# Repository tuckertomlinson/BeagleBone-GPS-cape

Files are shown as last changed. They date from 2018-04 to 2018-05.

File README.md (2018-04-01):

PCB layout for a GPS cape for the beaglebone black.

This is a home project. There is NO garauntee that the circuits do what
is intended, or that the function is adequately documented.

Any use of the files found in this project should be accompanied by a 
thorough review to determine proper function and fitness for use.

Project goals:
- clock discipline for the Beaglebone family such that a beaglebone with cape
	may act as an NTP stratum1 timeserver on a local network
- Use a GPS module to generate a 1 PPS signal that is synced to the atomic 
	clocks. The GPS module should interface with an active antenna so that
	good satellite lock may be attained indoors.
- provide an accurate RTC via a stand-alone i2c RTC module
- Hardware will be provided on a PCB cape, using SMT components for tight layout
	and low cost.
- Provide a hardware overlay file that may be enabled in uEnv.txt that will 
	automatically configure the correct pins for PPS capture, and RTC 
	connection

Stretch goals:
- Included a voltage regulated clock source, and force the BB to use the external 
	clock for better frequency stability

Current status:
- Proof of concept based on Adafruit Ultimate GPS breakout constructed and working
- 2 hardware capes designed
	- low cost cape based on Sierra Wireless XM1100 module
		- includeds RTC, and active antenna circuit
	- High cost cape based on uBlox LEA-M8T module
		- includes RTC, and 24Mhz VCTCXO clock. 
		- GPS module provides active antenna power
- Capes use Uart 4 to recieve GPS packets, and timer4 to take in PPS
- RTC is on i2c 1

Both capes completely untested.

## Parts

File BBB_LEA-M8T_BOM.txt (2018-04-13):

BeagleBone LEA-M8T GPS timing cape BOM:
notes: 
1)almost no effort was given here to cost optimization. Caps and resistors may likely be substituted for alternative components at lower cost. 
2)cost reflects prices on Digikey as of the time that this BOM was compiled. Prices reflect single part quantity. discounts for bulk purchases are not taken into account

part: 			board ID			manuf		manuf. #		digikey#		cost Apr 2018 	link
GPS module		U$1				uBlox		LEA-M8T			672-1067-1-ND 		$89		https://www.digikey.com/product-detail/en/u-blox-america-inc/LEA-M8T/672-1067-1-ND/7931818
.01uF cap 0805		C1,C4,C6,C9,C10,C13,C16,C18	TDK		CGA4J2X8R1H104K125AA 	445-5909-1-ND 		$0.22		https://www.digikey.com/product-detail/en/tdk-corporation/CGA4J2X8R1H104K125AA/445-5909-1-ND/2443949
10uF cap 0805		C2,C3,C5,C7,C11,C12,C14,C15,C17	TDK		C2012X7R1A106K125AE 	445-173616-1-ND		$0.46		https://www.digikey.com/product-detail/en/tdk-corporation/C2012X7R1A106K125AE/445-173616-1-ND/5809687
10nF cap 0805		C8				TDK		C2012X7R2E103K125AA 	445-2280-1-ND 		$0.21		https://www.digikey.com/product-detail/en/tdk-corporation/C2012X7R2E103K125AA/445-2280-1-ND/789789	
10kohm Resistor 0805	R2,R3,R4,R5			Panasonic	ERA-6AEB103V		P10KDACT-ND 		$0.36		https://www.digikey.com/product-detail/en/panasonic-electronic-components/ERA-6AEB103V/P10KDACT-ND/1465971
10 ohm Resistor 0805	R1				Vishay		TNPW080510R0FEEA	541-3916-1-ND 		$0.42		https://www.digikey.com/product-detail/en/vishay-dale/TNPW080510R0FEEA/541-3916-1-ND/7355274
Ferrite bead	0603	FB1,FB2,FB3,FB4,FB5		Laird		HI0805O121R-10		240-2393-1-ND		$0.11		https://www.digikey.com/product-detail/en/laird-signal-integrity-products/HI0805O121R-10/240-2393-1-ND/806753
3.3V regulator		U2				Microchip 	MIC5225-3.3		576-2980-1-ND 		$0.41		https://www.digikey.com/product-detail/en/microchip-technology/MIC5225-3.3YM5-TR/576-2980-1-ND/1815455
RTC			DS3231				Maxim		Ds3231MZ+		DS3231MZ+-ND		$7.72		https://www.digikey.com/product-detail/en/maxim-integrated/DS3231MZ/DS3231MZ-ND/2754396
24Mhz VCTCXO		U$3				Taitien		TWEAALSANF-24.000000	1664-1226-ND		$9.81		https://www.digikey.com/product-detail/en/taitien/TWEAALSANF-24.000000/1664-1226-ND/6127033
U.FL Antenna jack	U$20				TE Connectivity	1909763-1 		 A118077CT-ND		$0.49		https://www.digikey.com/product-detail/en/te-connectivity-amp-connectors/1909763-1/A118077CT-ND/4729711	
2X pinhdr 2x23		U$15				Samtec		SSQ-123-03-G-D		SAM1196-23-ND		$9.11		https://www.digikey.com/product-detail/en/samtec-inc/SSQ-123-03-G-D/SAM1196-23-ND/1111439  alt: https://www.adafruit.com/product/706
Diode			D1				Diodes Inc	1N4148WS-7-F		1N4148WS-FDICT-ND	$0.19		https://www.digikey.com/product-detail/en/diodes-incorporated/1N4148WS-7-F/1N4148WS-FDICT-ND/815281
Diode			D2				Toshiba		CUS520,H3F		CUS520H3FCT-ND		$0.22		https://www.digikey.com/product-detail/en/toshiba-semiconductor-and-storage/CUS520H3F/CUS520H3FCT-ND/5114381
CR1220 batt. holder	B1				MPD		BK-885 			BK-885-ND		$0.35		https://www.digikey.com/products/en?keywords=3001k-nd

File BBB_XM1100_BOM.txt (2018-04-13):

BeagleBone LEA-M8T GPS timing cape BOM:
notes: 
1)almost no effort was given here to cost optimization. Caps and resistors may likely be substituted for alternative components at lower cost. 
2)cost reflects prices on Digikey as of the time that this BOM was compiled. Prices reflect single part quantity. discounts for bulk purchases are not taken into account

part: 			board ID			manuf		manuf. #		digikey#		cost Apr 2018 	link
GPS module		U$3				Sierra		XXM1100_1103874		 1645-1040-1-ND 	$12.98		https://www.digikey.com/product-detail/en/sierra-wireless/XM1100_1103874/1645-1040-1-ND/7801768		
10uF cap 0805		C1,C2,C3,C6			TDK		C2012X7R1A106K125AE 	445-173616-1-ND		$0.46		https://www.digikey.com/product-detail/en/tdk-corporation/C2012X7R1A106K125AE/445-173616-1-ND/5809687
0.1uF cap 0805		C5,C7				TDK		CGA4J2X8R1H104K125AA 	445-5909-1-ND 		$0.22		https://www.digikey.com/product-detail/en/tdk-corporation/CGA4J2X8R1H104K125AA/445-5909-1-ND/2443949
47pF cap 0805		C4				ATC		600F470FT250XT  	1284-1061-1-ND 		$2.25		https://www.digikey.com/product-detail/en/american-technical-ceramics/600F470FT250XT/1284-1061-1-ND/3905433	
10kohm Resistor 0805	R1,R2,R3,R4,R5			Panasonic	ERA-6AEB103V		P10KDACT-ND 		$0.36		https://www.digikey.com/product-detail/en/panasonic-electronic-components/ERA-6AEB103V/P10KDACT-ND/1465971
10 ohm Resistor 0805	R6				Vishay		TNPW080510R0FEEA	541-3916-1-ND 		$0.42		https://www.digikey.com/product-detail/en/vishay-dale/TNPW080510R0FEEA/541-3916-1-ND/7355274
Ferrite bead	0805	FB1,FB2				Laird		HI0805O121R-10		240-2393-1-ND		$0.11		https://www.digikey.com/product-detail/en/laird-signal-integrity-products/HI0805O121R-10/240-2393-1-ND/806753
39nH inductor 0805	L1				Abracon		AISC-0805HQ-39NJ-T	535-12362-1-ND		$0.40		https://www.digikey.com/product-detail/en/murata-electronics-north-america/LQW18ANR15J8ZD/490-15773-1-ND/6800438
3.3V regulator		U2				Microchip 	MIC5225-3.3		576-2980-1-ND 		$0.41		https://www.digikey.com/product-detail/en/microchip-technology/MIC5225-3.3YM5-TR/576-2980-1-ND/1815455
RTC			DS3231				Maxim		Ds3231MZ+		DS3231MZ+-ND		$7.72		https://www.digikey.com/product-detail/en/maxim-integrated/DS3231MZ/DS3231MZ-ND/2754396
U.FL Antenna jack	U$20				TE Connectivity	1909763-1 		 A118077CT-ND		$0.49		https://www.digikey.com/product-detail/en/te-connectivity-amp-connectors/1909763-1/A118077CT-ND/4729711	
2X pinhdr 2x23		U$15				Samtec		SSQ-123-03-G-D		SAM1196-23-ND		$9.11		https://www.digikey.com/product-detail/en/samtec-inc/SSQ-123-03-G-D/SAM1196-23-ND/1111439  alt: https://www.adafruit.com/product/706
Diode			D1				Diodes Inc	1N4148WS-7-F		1N4148WS-FDICT-ND	$0.19		https://www.digikey.com/product-detail/en/diodes-incorporated/1N4148WS-7-F/1N4148WS-FDICT-ND/815281
Diode			D2				Toshiba		CUS520,H3F		CUS520H3FCT-ND		$0.22		https://www.digikey.com/product-detail/en/toshiba-semiconductor-and-storage/CUS520H3F/CUS520H3FCT-ND/5114381
CR1220 batt. holder	B1				MPD		BK-885 			BK-885-ND		$0.35		https://www.digikey.com/products/en?keywords=3001k-nd

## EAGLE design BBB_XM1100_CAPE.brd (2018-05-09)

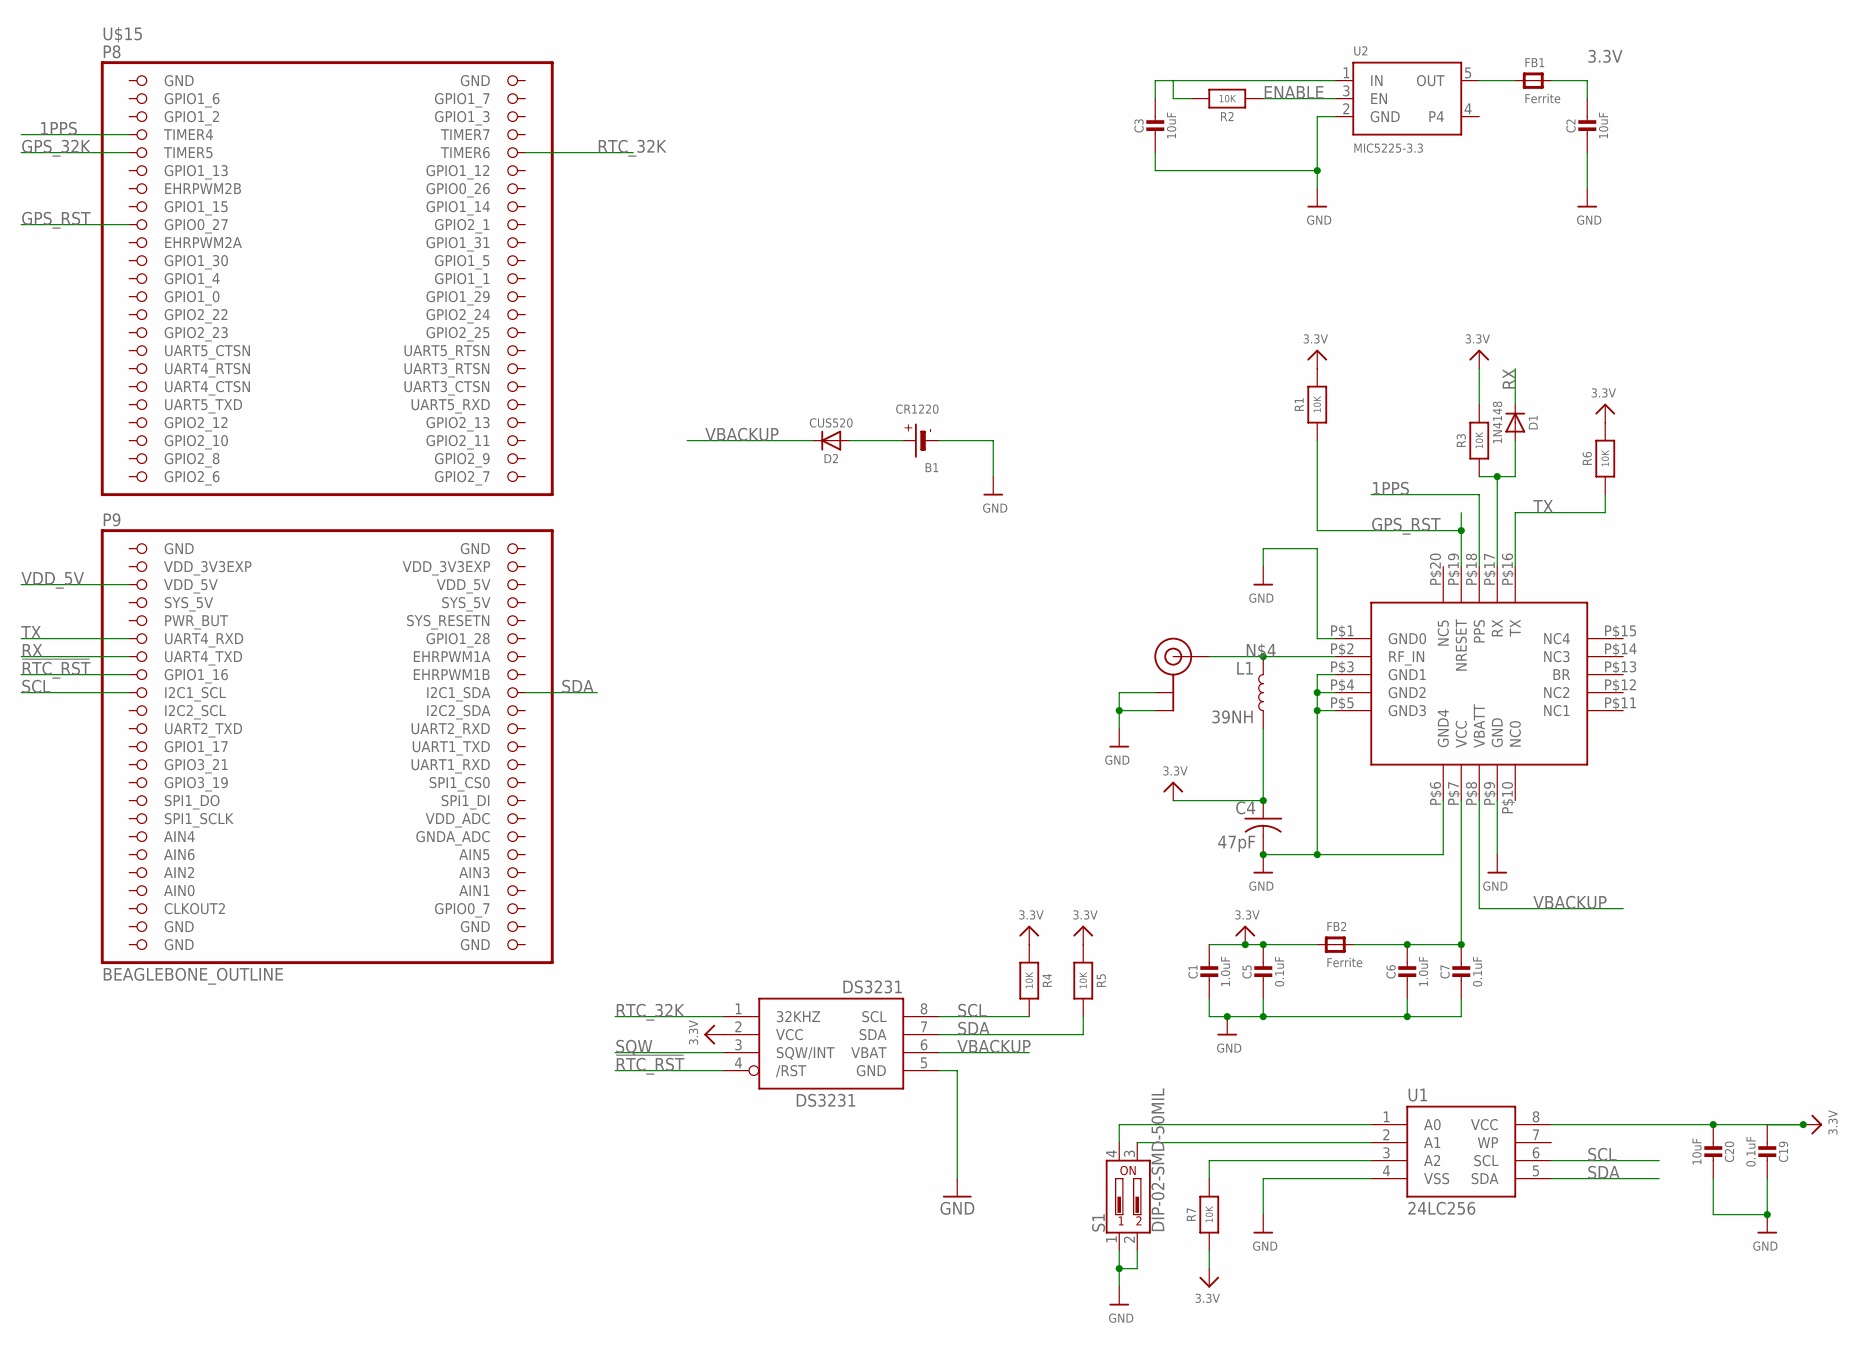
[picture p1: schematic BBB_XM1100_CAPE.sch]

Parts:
B1: CR1220
C1, C6: 1.0uF; 0805-NO
C2, C3, C20: 10uF; 0805-NO
C4: 47pF; C0805
C5, C7, C19: 0.1uF; 0805-NO
D1: 1N4148; SOD-323
D2: CUS520; SOD-323
DS3231: DS3231M-8PIN; SO08
FB1, FB2: Ferrite; 0805-NO@1
L1: 39NH; 0402
R1, R2, R3, R4, R5, R6, R7: 10K; 0805-NO
S1: DIP-02-SMD-50MIL; DIPSWITCH-02-50MIL
U1: 24LC256; SO08
U2: MIC5225-3.3; SOT23-5
U$3: XM1100
U$15: BEAGLEBONE_OUTLINE; BEAGLEBONE_SHIELD
U$20: U.FL

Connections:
1PPS: U$3.P$18 (PPS), U$15.7 (TIMER4)
3.3V: C1.1, C2.1, C4.1, C5.1, C19.1, C20.1, DS3231.2 (VCC), FB1.2, FB2.1, L1.2, R1.1, R3.1, R4.1, R5.1, R6.1, R7.1, U1.8 (VCC)
!RTC_RST: DS3231.4 (/RST), U$15.61 (GPIO1_16)
AIN0: U$15.85 (AIN0)
ENABLE: R2.1, U2.3 (EN)
GND: B1.-, C1.2, C2.2, C3.2, C4.2, C5.2, C6.2, C7.2, C19.2, C20.2, DS3231.5 (GND), S1.1, S1.2, U1.4 (VSS), U2.2 (GND), U$3.P$1 (GND0), U$3.P$3 (GND1), U$3.P$4 (GND2), U$3.P$5 (GND3), U$3.P$6 (GND4), U$3.P$9 (GND), U$15.1 (GND), U$15.2 (GND), U$15.47 (GND), U$15.48 (GND), U$15.89 (GND), U$15.90 (GND), U$15.91 (GND), U$15.92 (GND), U$20.P$1 (GND), U$20.P$2 (GND)
GPS_32K: U$15.9 (TIMER5)
GPS_RST: R1.2, U$3.P$19 (NRESET), U$15.17 (GPIO0_27)
unnamed: B1.+$1 (+), D2.A
unnamed: FB1.1, U2.5 (OUT)
unnamed: L1.1, U$3.P$2 (RF_IN), U$20.P$3 (SIGNAL)
unnamed: C6.1, C7.1, FB2.2, U$3.P$7 (VCC)
unnamed: R7.2, U1.3 (A2)
unnamed: S1.3, U1.2 (A1)
unnamed: S1.4, U1.1 (A0)
RTC_32K: DS3231.1 (32KHZ), U$15.10 (TIMER6)
RX: D1.C, U$15.59 (UART4_TXD)
RX_3V: D1.A, R3.2, U$3.P$17 (RX)
SCL: DS3231.8 (SCL), R4.2, U1.6 (SCL), U$15.63 (I2C1_SCL)
SDA: DS3231.7 (SDA), R5.2, U1.5 (SDA), U$15.64 (I2C1_SDA)
SQW: DS3231.3 (SQW/INT)
SYS_5V: U$15.53 (SYS_5V)
TX: R6.2, U$3.P$16 (TX), U$15.57 (UART4_RXD)
VBACKUP: D2.C, DS3231.6 (VBAT), U$3.P$8 (VBATT)
VDD_3V3EXP: U$15.49 (VDD_3V3EXP), U$15.50 (VDD_3V3EXP)
VDD_5V: C3.1, R2.2, U2.1 (IN), U$15.51 (VDD_5V), U$15.52 (VDD_5V)

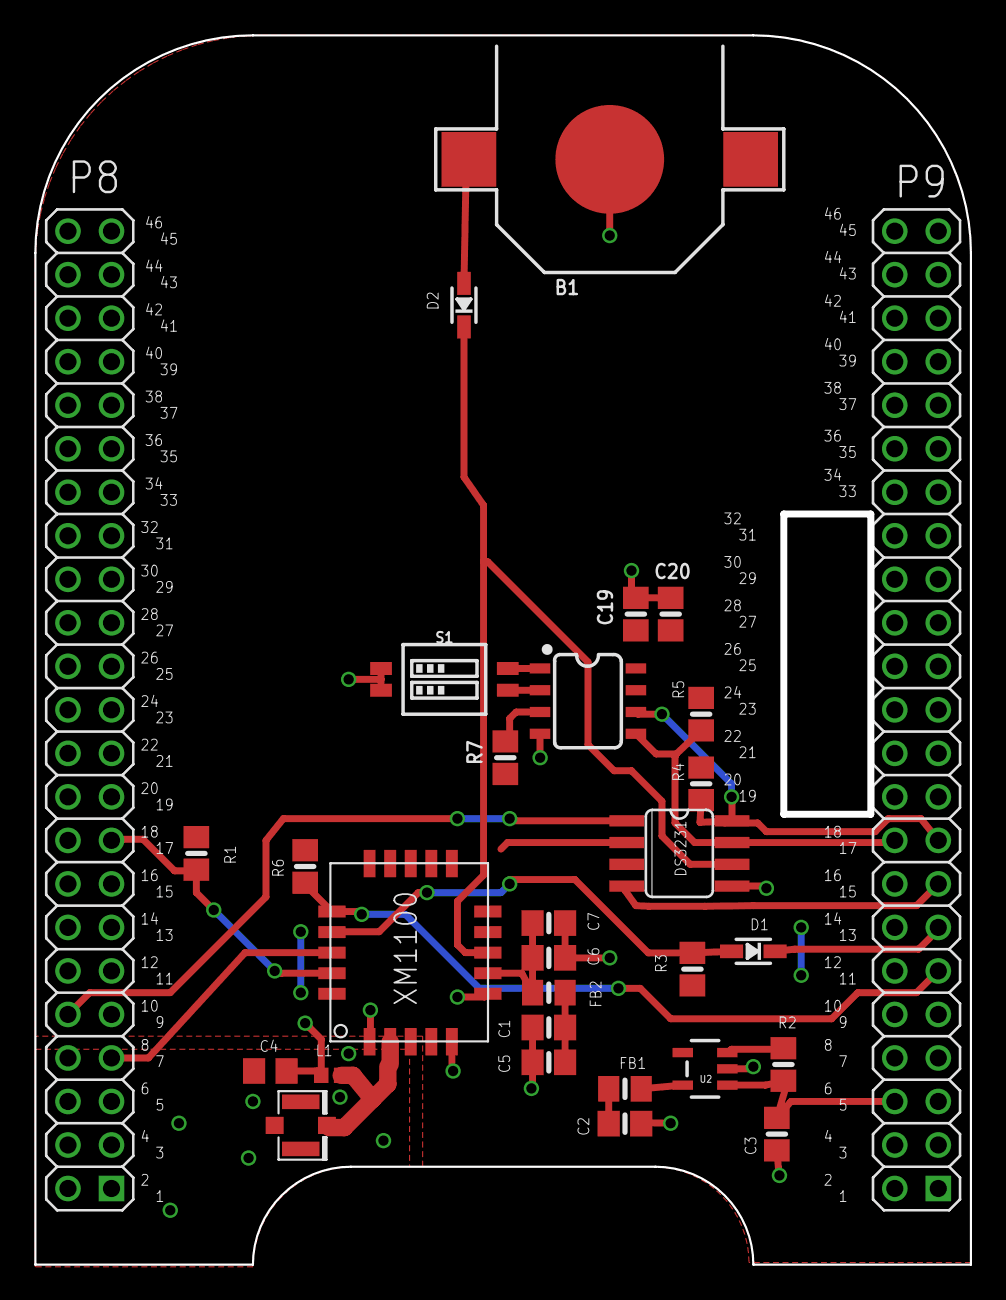
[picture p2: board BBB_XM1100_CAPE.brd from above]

Board: 2 copper layers, 54.6 x 71.8 mm, 29 parts (0 on the bottom side), 22 nets.

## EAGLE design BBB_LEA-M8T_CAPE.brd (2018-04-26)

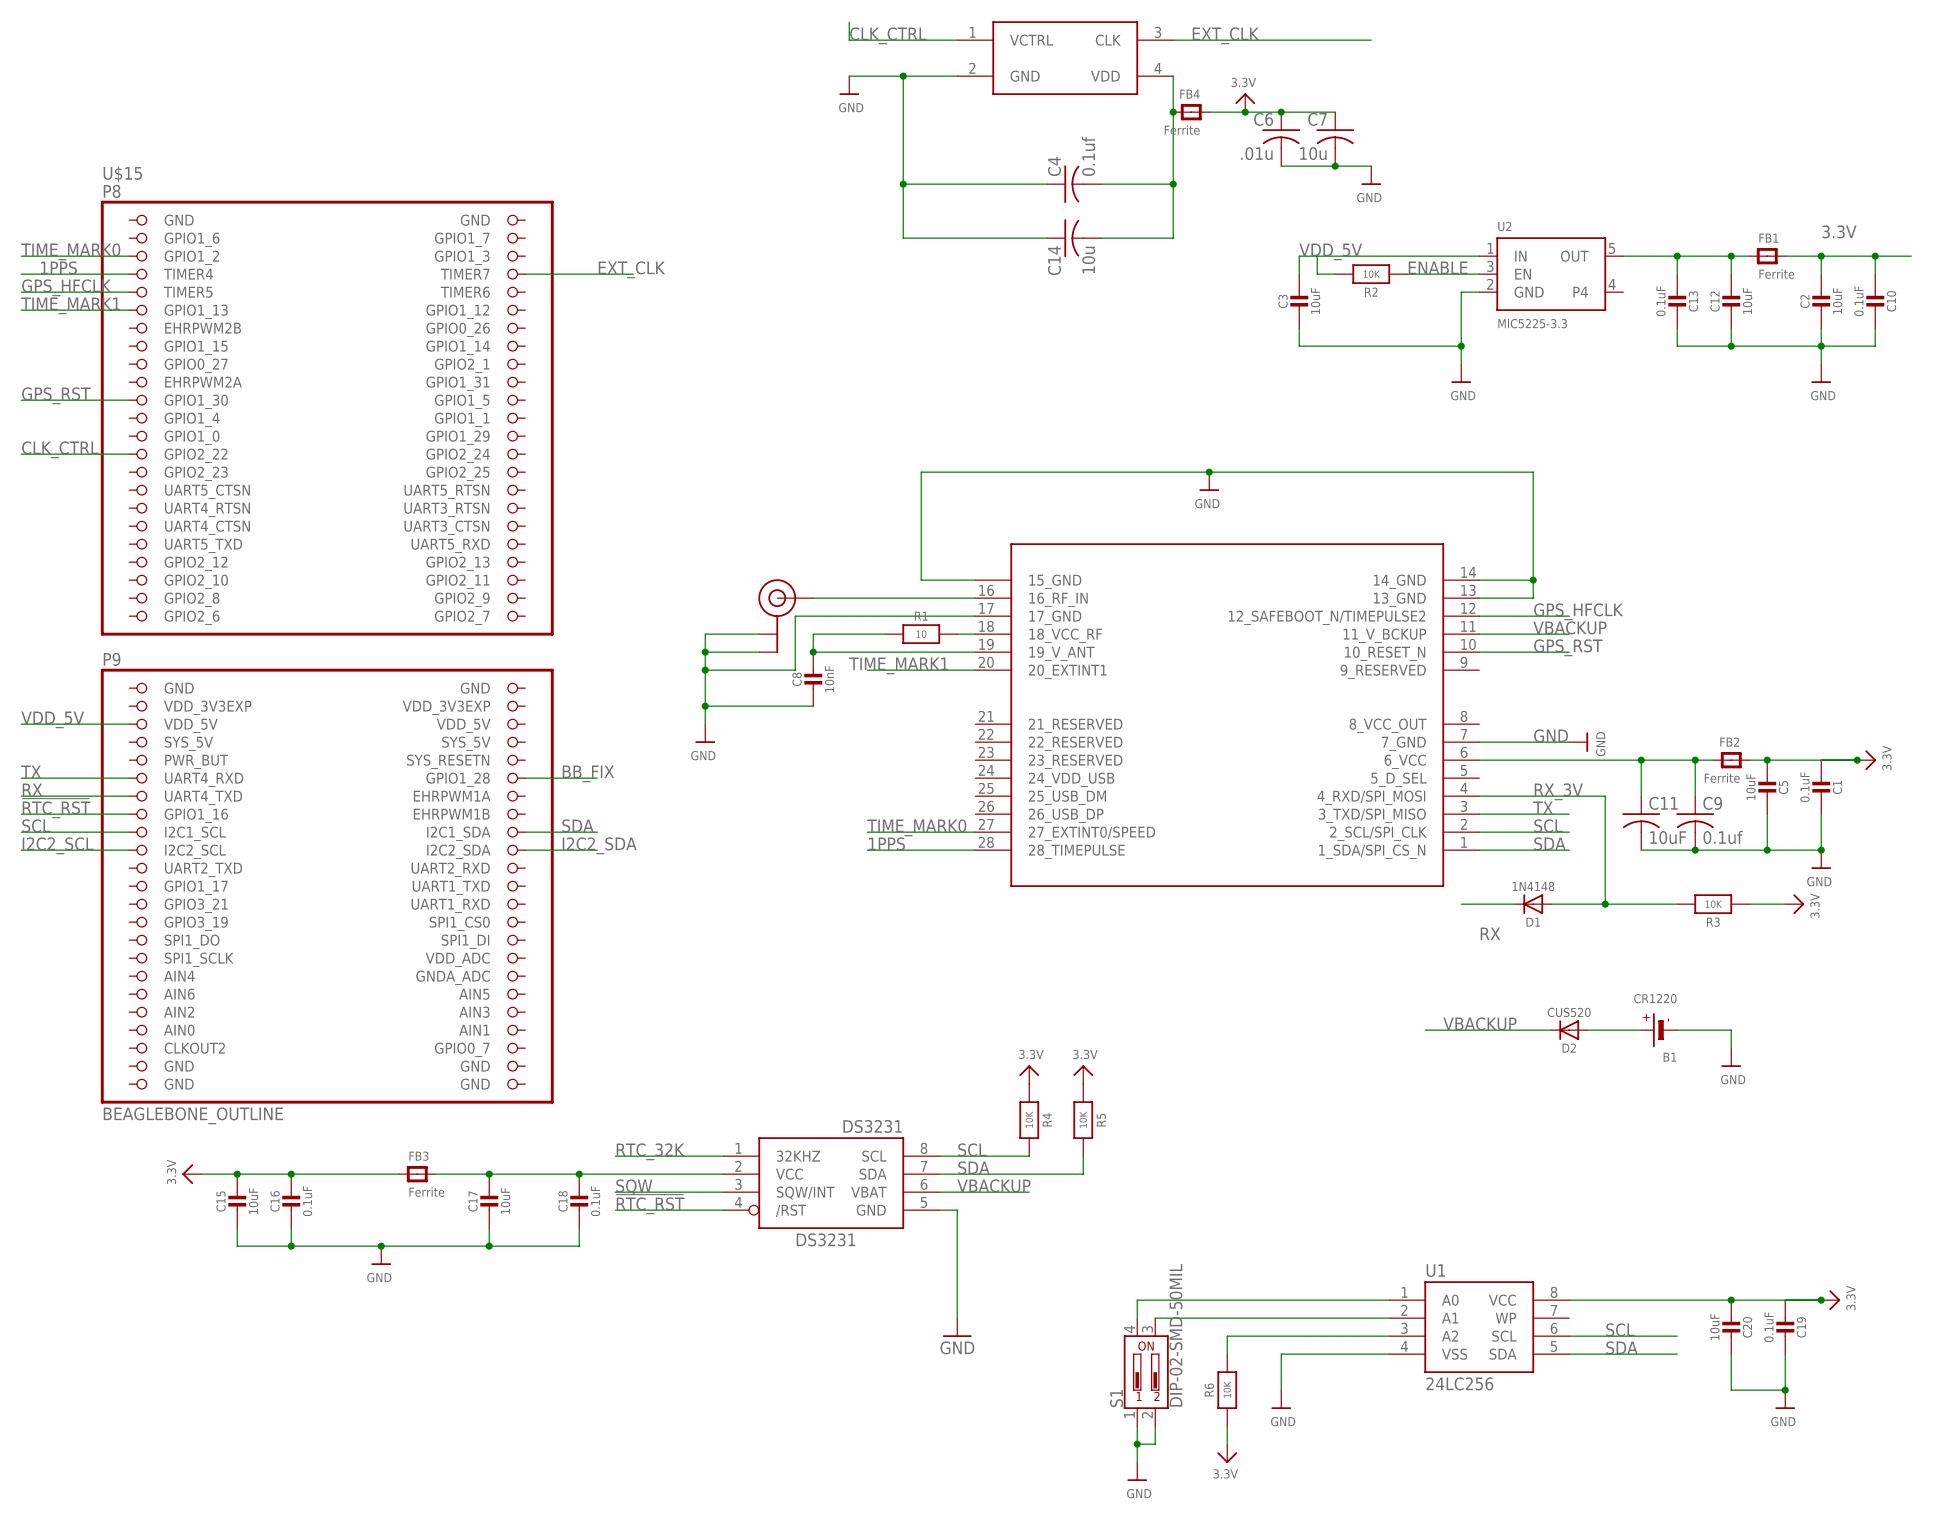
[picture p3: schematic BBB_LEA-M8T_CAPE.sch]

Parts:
B1: CR1220
C1, C10, C13, C16, C18, C19: 0.1uF; 0805-NO
C2, C3, C5, C12, C15, C17, C20: 10uF; 0805-NO
C4, C9: 0.1uf; C0805
C6: .01u; C0805
C7, C14: 10u; C0805
C8: 10nF; 0805-NO
C11: 10uF; C0805
D1: 1N4148; SOD-323
D2: CUS520; SOD-323
DS3231: DS3231M-8PIN; SO08
FB1, FB2, FB3, FB4: Ferrite; 0805-NO@1
R1: 10; 0805-NO
R2, R3, R4, R5, R6: 10K; 0805-NO
S1: DIP-02-SMD-50MIL; DIPSWITCH-02-50MIL
U1: 24LC256; SO08
U2: MIC5225-3.3; SOT23-5
U$1: LEA-M8
U$3: TAITIEN_TW-SERIES_OSCILLATOR
U$15: BEAGLEBONE_OUTLINE; BEAGLEBONE_SHIELD
U$20: U.FL

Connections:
1PPS: U$1.28 (28_TIMEPULSE), U$15.7 (TIMER4)
3.3V: C1.1, C2.1, C5.1, C6.1, C7.1, C10.1, C15.1, C16.1, C19.1, C20.1, FB1.2, FB2.1, FB3.1, FB4.1, R3.1, R4.1, R5.1, R6.1, U1.8 (VCC)
!RTC_RST: DS3231.4 (/RST), U$15.61 (GPIO1_16)
AIN0: U$15.85 (AIN0)
BB_FIX: U$15.58 (GPIO1_28)
CLK_CTRL: U$3.1 (VCTRL), U$15.27 (GPIO2_22)
ENABLE: R2.1, U2.3 (EN)
EXT_CLK: U$3.3 (CLK), U$15.8 (TIMER7)
GND: B1.-, C1.2, C2.2, C3.2, C4.1, C5.2, C6.2, C7.2, C8.2, C9.2, C10.2, C11.2, C12.2, C13.2, C14.1, C15.2, C16.2, C17.2, C18.2, C19.2, C20.2, DS3231.5 (GND), S1.1, S1.2, U1.4 (VSS), U2.2 (GND), U$1.7 (7_GND), U$1.13 (13_GND), U$1.14 (14_GND), U$1.15 (15_GND), U$1.17 (17_GND), U$3.2 (GND), U$15.1 (GND), U$15.2 (GND), U$15.47 (GND), U$15.48 (GND), U$15.89 (GND), U$15.90 (GND), U$15.91 (GND), U$15.92 (GND), U$20.P$1 (GND), U$20.P$2 (GND)
GPS_HFCLK: U$1.12 (12_SAFEBOOT_N/TIMEPULSE2), U$15.9 (TIMER5)
GPS_RST: U$1.10 (10_RESET_N), U$15.21 (GPIO1_30)
I2C2_SCL: U$15.65 (I2C2_SCL)
I2C2_SDA: U$15.66 (I2C2_SDA)
unnamed: B1.+$1 (+), D2.A
unnamed: C9.1, C11.1, FB2.2, U$1.6 (6_VCC)
unnamed: C12.1, C13.1, FB1.1, U2.5 (OUT)
unnamed: U$1.16 (16_RF_IN), U$20.P$3 (SIGNAL)
unnamed: C4.2, C14.2, FB4.2, U$3.4 (VDD)
unnamed: C17.1, C18.1, DS3231.2 (VCC), FB3.2
unnamed: R6.2, U1.3 (A2)
unnamed: S1.3, U1.2 (A1)
unnamed: S1.4, U1.1 (A0)
unnamed: R1.2, U$1.18 (18_VCC_RF)
unnamed: C8.1, R1.1, U$1.19 (19_V_ANT)
RTC_32K: DS3231.1 (32KHZ)
RX: D1.C, U$15.59 (UART4_TXD)
RX_3V: D1.A, R3.2, U$1.4 (4_RXD/SPI_MOSI)
SCL: DS3231.8 (SCL), R4.2, U1.6 (SCL), U$1.2 (2_SCL/SPI_CLK), U$15.63 (I2C1_SCL)
SDA: DS3231.7 (SDA), R5.2, U1.5 (SDA), U$1.1 (1_SDA/SPI_CS_N), U$15.64 (I2C1_SDA)
SQW: DS3231.3 (SQW/INT)
SYS_5V: U$15.53 (SYS_5V)
TIME_MARK0: U$1.27 (27_EXTINT0/SPEED), U$15.5 (GPIO1_2)
TIME_MARK1: U$1.20 (20_EXTINT1), U$15.11 (GPIO1_13)
TX: U$1.3 (3_TXD/SPI_MISO), U$15.57 (UART4_RXD)
VBACKUP: D2.C, DS3231.6 (VBAT), U$1.11 (11_V_BCKUP)
VDD_3V3EXP: U$15.49 (VDD_3V3EXP), U$15.50 (VDD_3V3EXP)
VDD_5V: C3.1, R2.2, U2.1 (IN), U$15.51 (VDD_5V), U$15.52 (VDD_5V)

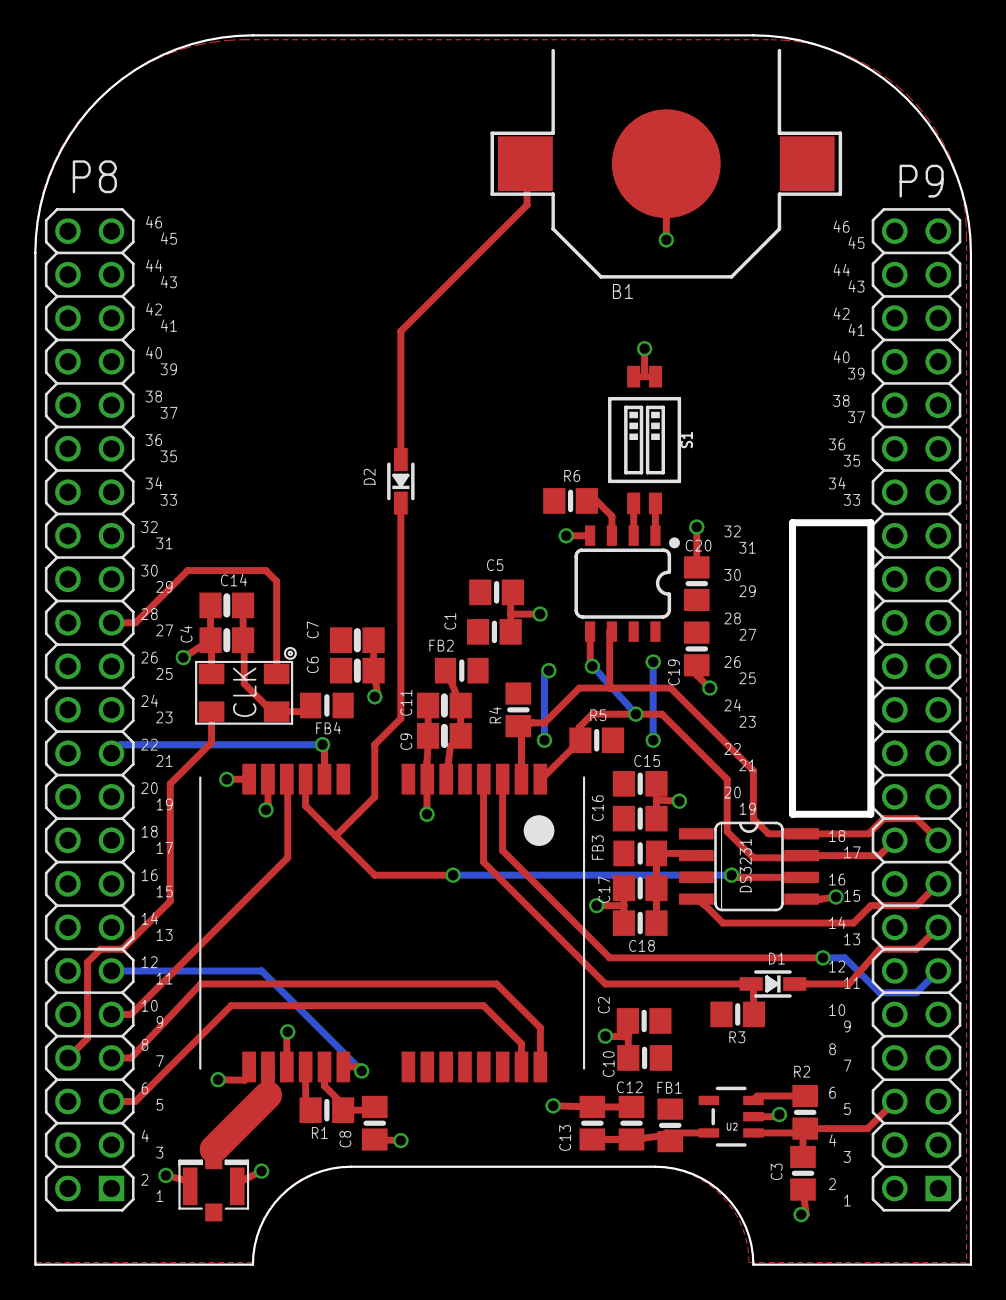
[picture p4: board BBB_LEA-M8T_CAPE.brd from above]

Board: 2 copper layers, 54.6 x 71.8 mm, 41 parts (0 on the bottom side), 30 nets.

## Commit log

2018-04-01 initial commit. First pass at layout, and a readme
    [BBB_LEA-M8T_CAPE.brd, BBB_LEA-M8T_CAPE.sch, BBB_XM1100_CAPE.brd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]
2018-04-02 layout changes. Added filtering to LEA schematic. Added BOM for both schematics
2018-04-02 moved errant wire on XM1100 layout
    [BBB_XM1100_CAPE.brd]
2018-04-02 moved battery for cleaner layout on XM1100
2018-04-12 BOM updates associated with populating first test boards
    [BBB_LEA-M8T_CAPE.brd, BBB_LEA-M8T_CAPE.sch, BBB_XM1100_CAPE.brd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]
2018-04-13 minor updates to silkscreen layout to better match OSH Park silkscreen resolution
    [BBB_LEA-M8T_CAPE.brd, BBB_XM1100_CAPE.brd]
2018-04-13 minor layout and silkscreen cleanup
    [BBB_LEA-M8T_CAPE.brd, BBB_XM1100_CAPE.brd]
2018-04-26 added eeprom to ublox LEA cape
    [BBB_LEA-M8T_CAPE.brd, BBB_LEA-M8T_CAPE.sch]
2018-04-26 added eeprom to XM1100 cape
    [BBB_XM1100_CAPE.brd, BBB_XM1100_CAPE.sch]
2018-05-09 corrected error in VCC/GND connections on xm1100 cape
    [BBB_XM1100_CAPE.brd, BBB_XM1100_CAPE.sch]

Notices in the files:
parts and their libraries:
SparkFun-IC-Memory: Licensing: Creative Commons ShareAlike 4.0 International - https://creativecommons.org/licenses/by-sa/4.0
